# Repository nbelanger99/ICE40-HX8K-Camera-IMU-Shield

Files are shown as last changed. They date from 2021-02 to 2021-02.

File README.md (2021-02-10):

# ICE40-HX8K Camera & IMU Shield

This is an open-source shield designed for Lattice's [ICE-40 breakout board](http://www.latticesemi.com/en/Products/DevelopmentBoardsAndKits/iCE40HX8KBreakoutBoard.aspx) which has a single OV7690 & an IMU. It was developed to experiment with a hardware-accelerated Mono-SLAM algorithm, or other vision applications

As of yet; the verilog library needed to test the design has **not** been written. If a working module is developed, an [ICEStorm](https://github.com/YosysHQ/icestorm) project example will be open sourced and linked here. 

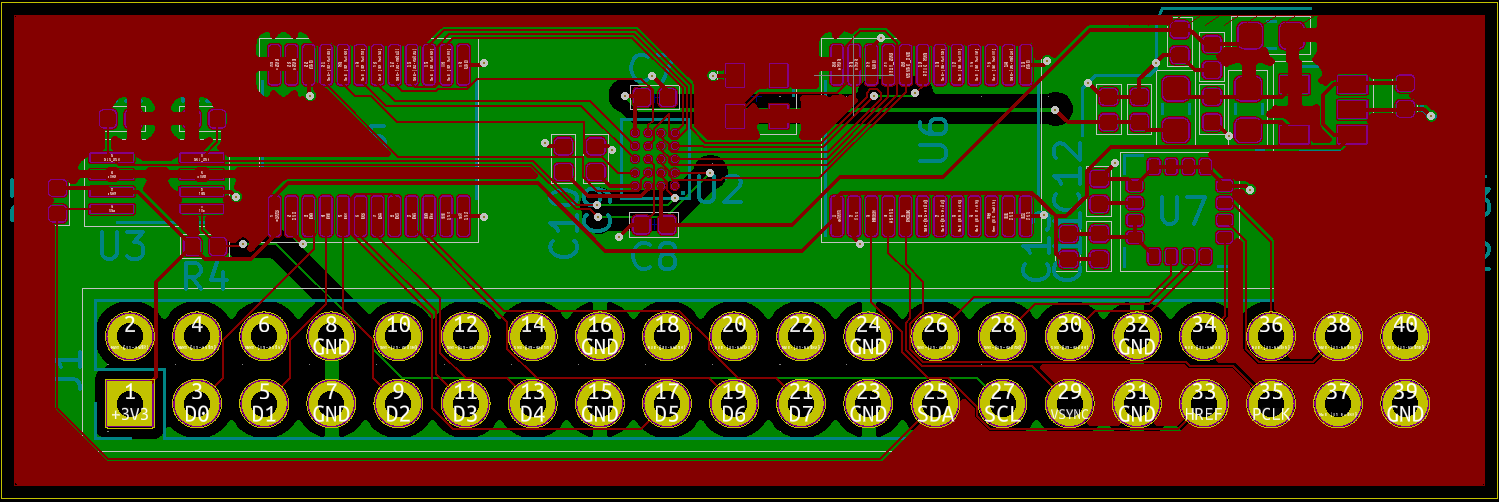
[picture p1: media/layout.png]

<br>
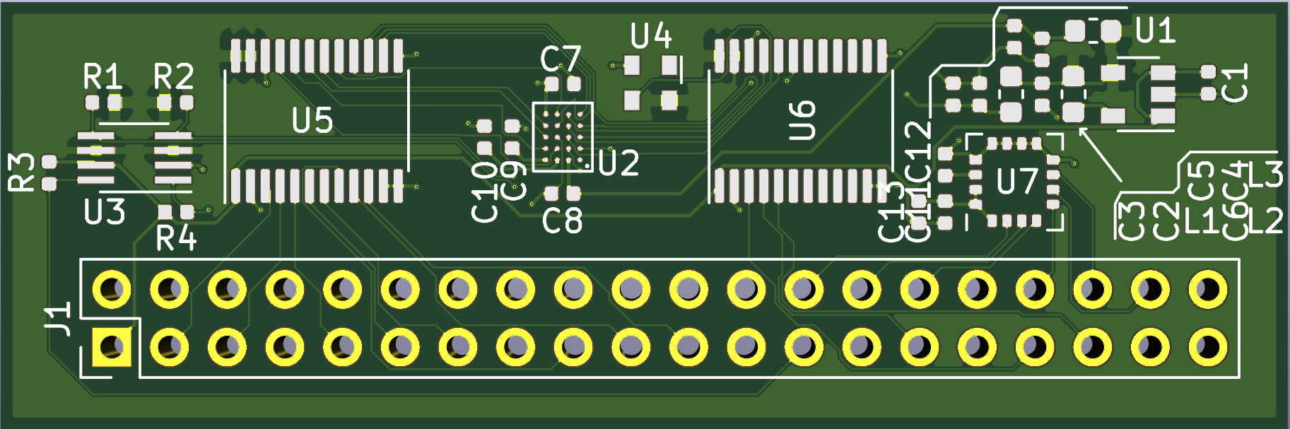
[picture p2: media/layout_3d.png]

<br>
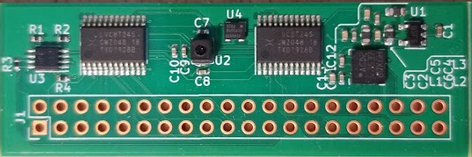
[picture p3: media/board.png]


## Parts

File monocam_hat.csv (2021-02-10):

Item # | *Designator | *Qty | Manufacturer | *Mfg Part # | Description / Value | *Package/Footprint | Type | Your Instructions / Notes
1 | U7 | 1 | ST | L3GD20 | IC MEMS MOTION SENSOR 16LLGA | LGA-16_4x4mm_P0.65mm_LayoutBorder4x4y | Surface Mount
2 | U6,U5 | 2 | Nexperia | 74LVC8T245PW,118 | IC TRNSLTR BIDIRECTIONAL 24TSSOP | TSSOP-24_4.4x7.8mm_P0.65mm | Surface Mount
3 | U4 | 1 | Abracon | ‎ASDMB-24.000MHZ-LC-T | MEMS OSC XO 24.0000MHZ LVCMOS | Oscillator_SMD_Abracon_ASDMB-4Pin_2.5x2.0mm | Surface Mount
4 | U3 | 1 | TI | ‎TXS0102DCTR‎ | IC TRNSLTR BIDIRECTIONAL SM8 | SSOP-8_2.95x2.8mm_P0.65mm | Surface Mount
5 | U2 | 1 | Omnivision | ‎OVM7690-R20A | SENSOR CAMERA CMOS 20CAMERACUBE | BGA-20_2.4x2.6mm_Layout4x5_P0.5mm | Surface Mount
6 | U1 | 1 | TI | ‎LM3671MF-2.8/NOPB‎ | IC REG BUCK 2.8V 600MA SOT23-5 | SOT-23-5 | Surface Mount
7 | R4,R3,R2,R1 | 4 | ‎Yageo‎ | ‎RC0402JR-074K7L‎ | RES SMD 4.7K OHM 5% 1/16W 0402 | R_0402_1005Metric | Surface Mount | Exact passive Component part numbers can be replaced with parts of same footprint and size at your convenience
8 | L3,L1 | 2 | Abracon | ‎AIML-0603-3R3K-T‎ | FIXED IND 3.3UH 15MA 1.55 OHM | L_0402_1005Metric | Surface Mount | Exact passive Component part numbers can be replaced with parts of same footprint and size at your convenience
9 | L2 | 1 | Abracon | ‎AIML-0603-2R2K-T | FIXED IND 2.2UH 15MA 1.15 OHM | L_0402_1005Metric | Surface Mount | Exact passive Component part numbers can be replaced with parts of same footprint and size at your convenience
10 | C12 | 1 | Yageo | CC0402KRX7R7BB103 | CAP CER 10000PF 16V X7R 0402 | C_0402_1005Metric | Surface Mount | Exact passive Component part numbers can be replaced with parts of same footprint and size at your convenience
11 | C11, C10,C9,C8,C7,C4,C2 | 6 | Samsung Electro-Mechanics | ‎CL05F104ZO5NNNC‎ | CAP CER 0.1UF 16V Y5V 0402 | C_0402_1005Metric | Surface Mount | Exact passive Component part numbers can be replaced with parts of same footprint and size at your convenience
12 | C13, C6,C5,C3 | 3 | Murata Electronics | ‎GRM155R60G106ME44D | CAP CER 10UF 4V X5R 0402 | C_0402_1005Metric | Surface Mount | Exact passive Component part numbers can be replaced with parts of same footprint and size at your convenience
13 | C1 | 1 | Murata Electronics | ‎GRM155R60J475ME47D‎ | CAP CER 4.7UF 6.3V X5R 0402 | C_0402_1005Metric | Surface Mount | Exact passive Component part numbers can be replaced with parts of same footprint and size at your convenience
 |  | 25

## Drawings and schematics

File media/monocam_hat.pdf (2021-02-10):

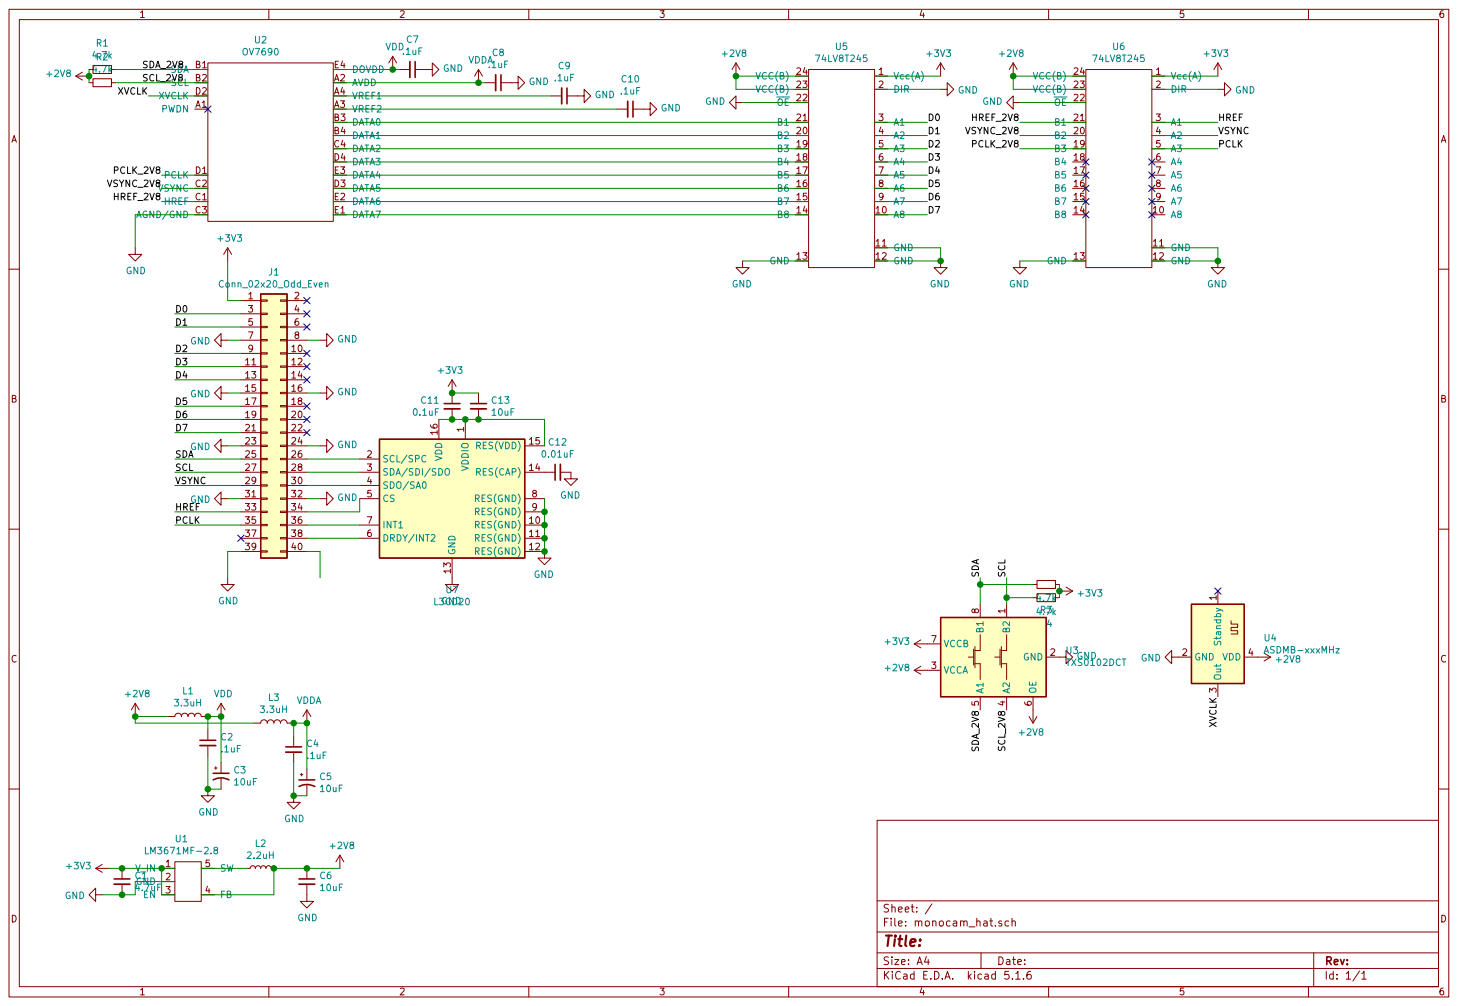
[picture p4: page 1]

1 RES(GND) 10 RES(GND) 11 RES(GND) 12 GND 13

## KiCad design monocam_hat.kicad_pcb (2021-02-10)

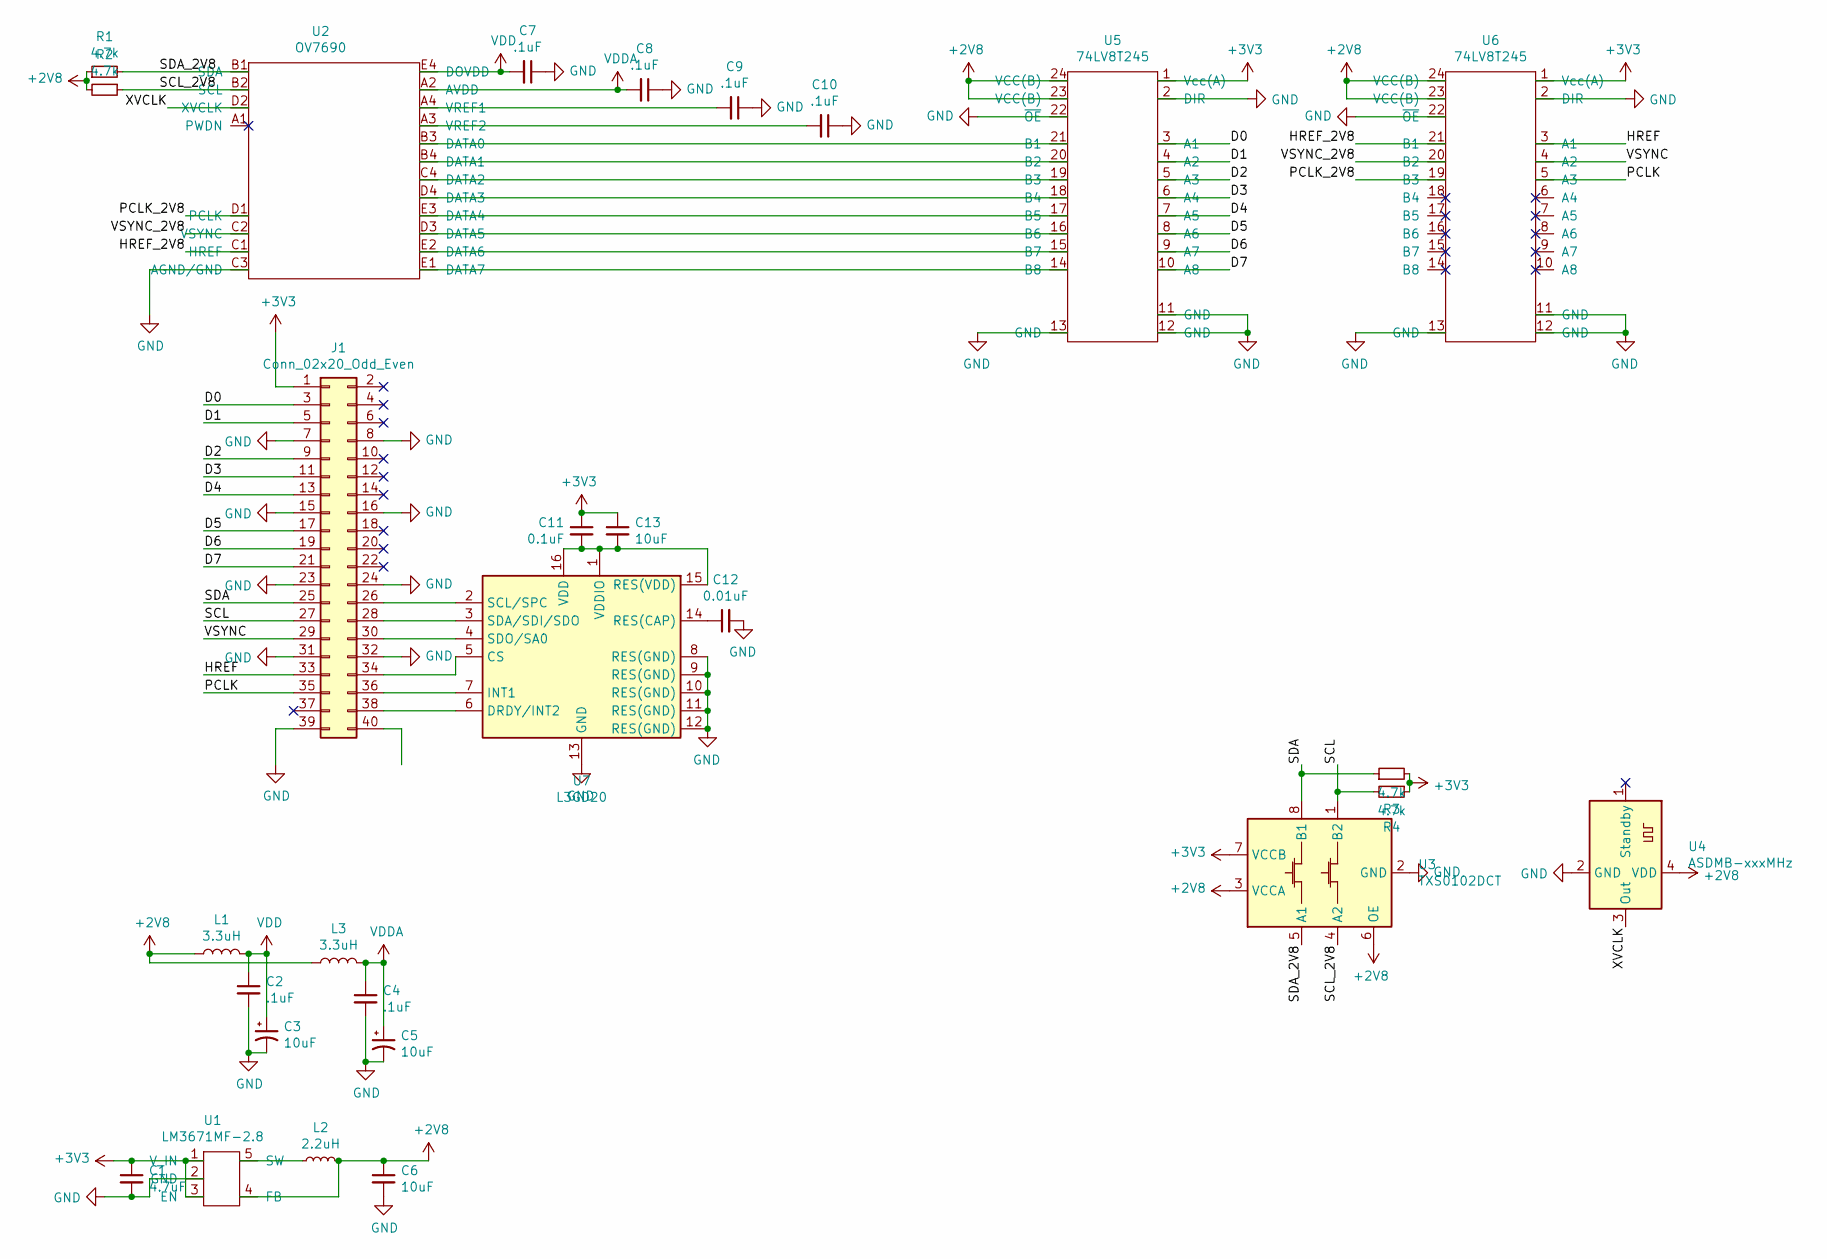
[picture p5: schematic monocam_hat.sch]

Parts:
C1: 4.7uF; C_0402_1005Metric
C2, C4, C7, C8, C9, C10: .1uF; C_0402_1005Metric
C3, C5, C6, C13: 10uF; C_0402_1005Metric
C11: 0.1uF; C_0402_1005Metric
C12: 0.01uF; C_0402_1005Metric
J1: Conn_02x20_Odd_Even; PinHeader_2x20_P2.54mm_Vertical
L1, L3: 3.3uH; L_0603_1608Metric
L2: 2.2uH; L_0603_1608Metric
R1, R2, R3, R4: 4.7k; R_0402_1005Metric
U1: LM3671MF-2.8; SOT-23-5
U2: OV7690; BGA-20_2.4x2.6mm_Layout4x5_P0.5mm_0.2mm_Pad
U3: TXS0102DCT; SSOP-8_2.95x2.8mm_P0.65mm
U4: ASDMB-xxxMHz; Oscillator_SMD_Abracon_ASDMB-4Pin_2.5x2.0mm
U5, U6: 74LV8T245; TSSOP-24_4.4x7.8mm_P0.65mm
U7: L3GD20; LGA-16_4x4mm_P0.65mm_LayoutBorder4x4y

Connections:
+2V8: C6.1, L1.1, L2.2, L3.1, R1.1, R2.2, U1.4 (FB), U3.3 (VCCA), U3.6 (OE), U4.4 (VDD), U5.23 (VCC(B)), U5.24 (VCC(B)), U6.23 (VCC(B)), U6.24 (VCC(B))
+3V3: C1.1, C11.1, C13.1, J1.1, R3.2, R4.1, U1.1 (V_IN), U1.3 (EN), U3.7 (VCCB), U5.1 (Vcc(A)), U6.1 (Vcc(A))
/D0: J1.3, U5.3 (A1)
/D1: J1.5, U5.4 (A2)
/D2: J1.9, U5.5 (A3)
/D3: J1.11, U5.6 (A4)
/D4: J1.13, U5.7 (A5)
/D5: J1.17, U5.8 (A6)
/D6: J1.19, U5.9 (A7)
/D7: J1.21, U5.10 (A8)
/HREF: J1.33, U6.3 (A1)
/HREF_2V8: U2.C1 (HREF), U6.21 (B1)
/PCLK: J1.35, U6.5 (A3)
/PCLK_2V8: U2.D1 (PCLK), U6.19 (B3)
/SCL: J1.27, R4.2, U3.1 (B2)
/SCL_2V8: R2.1, U2.B2 (SCL), U3.4 (A2)
/SDA: J1.25, R3.1, U3.8 (B1)
/SDA_2V8: R1.2, U2.B1 (SDA), U3.5 (A1)
/VSYNC: J1.29, U6.4 (A2)
/VSYNC_2V8: U2.C2 (VSYNC), U6.20 (B2)
/XVCLK: U2.D2 (XVCLK), U4.3 (Out)
GND: C1.2, C2.2, C3.2, C4.2, C5.2, C6.2, C7.1, C8.1, C9.1, C10.1, C12.2, J1.7, J1.8, J1.15, J1.16, J1.23, J1.24, J1.31, J1.32, J1.39, U1.2 (GND), U2.C3 (AGND/GND), U3.2 (GND), U4.2 (GND), U5.2 (DIR), U5.11 (GND), U5.12 (GND), U5.13 (GND), U5.22 (~OE), U6.2 (DIR), U6.11 (GND), U6.12 (GND), U6.13 (GND), U6.22 (~OE), U7.8 (RES(GND)), U7.9 (RES(GND)), U7.10 (RES(GND)), U7.11 (RES(GND)), U7.12 (RES(GND)), U7.13 (GND)
unnamed: C9.2, U2.A4 (VREF1)
unnamed: C10.2, U2.A3 (VREF2)
unnamed: C11.2, C13.2, U7.1 (VDDIO), U7.15 (RES(VDD)), U7.16 (VDD)
unnamed: C12.1, U7.14 (RES(CAP))
unnamed: J1.26, U7.2 (SCL/SPC)
unnamed: J1.28, U7.3 (SDA/SDI/SDO)
unnamed: J1.30, U7.4 (SDO/SA0)
unnamed: J1.34, U7.5 (CS)
unnamed: J1.36, U7.7 (INT1)
unnamed: J1.38, U7.6 (DRDY/INT2)
unnamed: L2.1, U1.5 (SW)
unnamed: U2.B3 (DATA0), U5.21 (B1)
unnamed: U2.B4 (DATA1), U5.20 (B2)
unnamed: U2.C4 (DATA2), U5.19 (B3)
unnamed: U2.D3 (DATA5), U5.16 (B6)
unnamed: U2.D4 (DATA3), U5.18 (B4)
unnamed: U2.E1 (DATA7), U5.14 (B8)
unnamed: U2.E2 (DATA6), U5.15 (B7)
unnamed: U2.E3 (DATA4), U5.17 (B5)
VDD: C2.1, C3.1, C7.2, L1.2, U2.E4 (DOVDD)
VDDA: C4.1, C5.1, C8.2, L3.2, U2.A2 (AVDD)

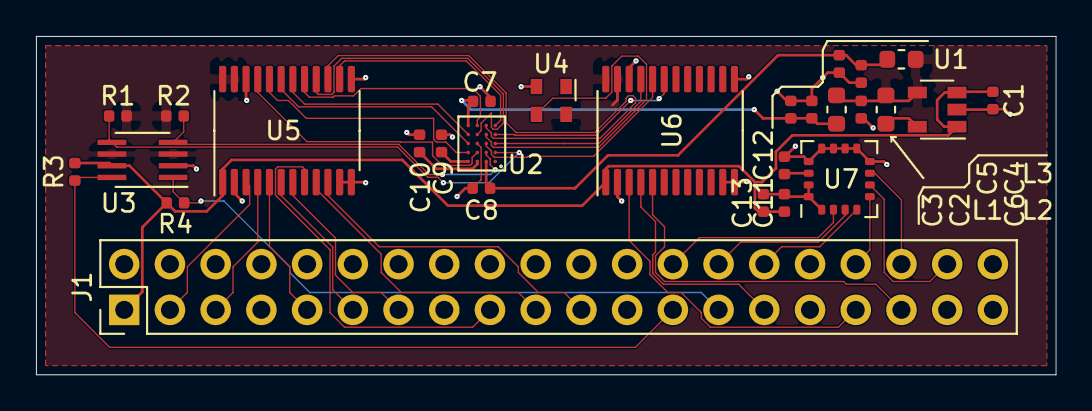
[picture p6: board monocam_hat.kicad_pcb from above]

Board: 2 copper layers, 56.6 x 18.8 mm, 28 parts (0 on the bottom side), 43 nets.

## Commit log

2020-08-31 v1 layout complete
    [monocam_hat.csv, monocam_hat.kicad_pcb, monocam_hat.sch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]
2021-02-10 Removing tracked gerbers and adding gitignore
    [monocam_hat-NPTH-drl_map.gbr, monocam_hat-NPTH.drl, monocam_hat-PTH-drl_map.gbr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]
2021-02-10 V2 layout complete
    [monocam_hat.csv, monocam_hat.kicad_pcb, monocam_hat.sch]
